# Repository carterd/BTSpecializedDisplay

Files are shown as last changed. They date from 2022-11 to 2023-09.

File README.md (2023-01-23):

# Bluetooth Specialized Display (https://https://github.com/carterd/BTSpecializedDisplay)

Ebike display for Specialized Turbo bikes, these include Kenevo/Levo/Creo.

# Configuration

If your using the Arduino IDE to compile the software you'll need to place each of the dependencies into the 'Arduino/library'
folder, and install the BTSpecializedDisplay project files into 'Arduino/BTSpecializedDisplay'. In addition you will need to 
copy the file "lv_conf.h" from of the location 'Arduino/library/BTSpecializedDisplay/lv_conf.h' to the location 
'Arduino/library/lv_conf.h'. This will ensure the lvgl library is configured correctly for RP2040 and Adafruit libraries.

Take special note of the version of LVGL your using ... if your decide to use the latest from the GIT repository you'll need
to make specific changes to the file 'Arduino/library/Adafruit_LvGL_Glue/src/Adafruit_LvGL_Glue.h', lines 4-5. 

# Dependencies
 
 * [ArduinoBLE (carterd version)](https://github.com/carterd/ArduinoBLE)

    As of writting this readme, ArduinoBLE 1.3.2 has a bug and needs patching hence clone the above branch into your
    Arduino/library path.

 * [Arduino LvGL Glue Library](https://github.com/carterd/Arduino_LvGL_Glue) 

    This is my own version of the Adafruit LvGL Glue, and hence you'll need to clone the branch to Arduino/library path.
    The library provides driver implementation for various graphics displays with LVGL.
    
 * [LittlevGL](https://github.com/littlevgl/lvgl)

    As of writting the code, the application has been written against version 8.3 of LVGL. Hence, I'd advise using the
    latest version 8.3.4 of LVGL (as of writting). Note, to copy the "lv_conf.h" out of Adafruit_LvGL_Glue above.
    
    You can use the latest lvgl source from github, but there has been a change to the debug API and hence this will 
    require you to patch my Adafruit LvGL Glue Library. Hence, if your not confident in coding skills then use LVGL version
    8.3.4.

 * [Adafruit GFX Library](https://github.com/adafruit/Adafruit-GFX-Library)

    As of writting the code, the application has been written against version 1.11.3 of Adafruit GFX Library. We'll need
    this to drive the Adafruit OLED 128x64 FeatherWing.

 * [Adafruit SH110X Library](https://github.com/adafruit/Adafruit_SH110X)

    As of writting the code, the application has been written against version 2.1.6 of Adafruit SH110X Library. We'll need
    this to drive the SH110X display. Hence other types of display may mean you don't require this library.

 * [Arduino Encorder](https://github.com/carterd/Arduino_Encoder)

    The LvGL library has a concept of an encoder, this library implements a generic framework for such an encoder as well
    as a three button encoder implementation which is compatable with the three buttons on the Adafruit OLED 128x64 FeatherWing.

 * [Adafruit_TouchScreen](https://github.com/adafruit/Adafruit_TouchScreen)

    When re-writting the Adafruit LvGL Glue Library, the touch-screen code was maintained, hence even though SH110X display
    has buttons and not touchscreen, some touch screen code is left in LvGL Glue Library and hence requires this library
    unless you explicitly remove these references to touch screens.

 * [MBED_RPI_PICO_TimerInterrupt](https://github.com/khoih-prog/MBED_RPI_PICO_TimerInterrupt)

    This is a required RP2040 specific library specifically to create an interrupt to update the LvGL timer.
 
 * [LittleFS_Mbed_RP2040](https://github.com/khoih-prog/LittleFS_Mbed_RP2040)

    AS of writting using version 1.1.0 of LittleFS_Mbed_RP2040. An implementation of a file-system on the RP2040 hence
    allowing configuration to be stored in the flash memory of the RP2040.

# Issues

The current BLE library has an issue in the file 'src/utility/ATT.cpp' function 'ATTClass::discoverDescriptors', 
until this is fixed used the patched branch at (https://github.com/carterd/ArduinoBLE).

The application has been written using a branched version of "Adafruit LvGL Glue Library" which differs significatly
hence care should be used to use the specific dependancy identified above.

# The Circuit

Please see [a relative link](circuit/Readme.md) for more details on the specifics of the hardware components and
details of wiring.

# The Enclosure

An example enclosure has been designed in Blender the assoicated .blend file of this enclosure can be found in the
directory ./enclosure, as well as a number of .STL files of the individual parts that comprise the
enclosure, see [a relative link](enclosure/Readme.md).

# Copyright Notice

Bluetooth Display for Specialized Turbo bikes
Copyright (C) 2022 Derek Carter

This program is free software: you can redistribute it and/or modify
it under the terms of the GNU General Public License as published by
the Free Software Foundation, either version 3 of the License, or
(at your option) any later version.

This program is distributed in the hope that it will be useful,
but WITHOUT ANY WARRANTY; without even the implied warranty of
MERCHANTABILITY or FITNESS FOR A PARTICULAR PURPOSE.  See the
GNU General Public License for more details.

You should have received a copy of the GNU General Public License
along with this program.  If not, see <http://www.gnu.org/licenses/>.

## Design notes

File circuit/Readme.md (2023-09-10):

# Bluetooth Specialized Display Circuit Diagram (https://github.com/carterd/BTSpecializedDisplay)

I've created a number of versions of the Bluetooth Specialized Display based on the the following:

 * Arduino Nano RP2040 Connect

 * TTGO T-Display

 * T-Display-S3

Each circuit is designed to plug into the Brose motors which are compatable with 6v lights. The compatibility 
for such motors can be found here for the Lupine lights https://www.lupine.de/eng/service/downloads/66-3.

Therefore we see that if we limit the Display circuit to max of 6v input the circuit is compatible with:

 * Gen 1 Motors
 * Gen 1.2 / 1.2E / 1.2S Motors
 * Gen 1.3 Motors

# Converting to use universal E-Bike connectors

In order to give a cheap universal connection for display and lights a Brose to universal E-Bike connector
lead can be implemented as follows:

```
Two pin E-bike "RED" connector

               ┌────────┐─────┐                            ┌────┌─────────┐     ┌────────┐─────┐
              ┌┘        └┐    └┐ 6V (Red)         (White) ┌┘   ┌┘         └┐   ┌┘        └┐    └┐ 6V (White)     
              │    ===== │     ├──────────────────────────┤    │     O     │   │    ===== │     ├───────────────────────   
     Brose    │         ┌┘     │                          │    │          ┌┘   └┐         │     │                           Bluetooth 
              │         │      │                          │    │          │     │         │     │
     Motor    │         └┐     │ 0V (Black)       (Black) │    │          └┐   ┌┘         │     │ 0V (Black)                Display
              │    ===== │     ├──────────────────────────┤    │     O     │   │    ===== │     ├───────────────────────   
              └┐        ┌┘    ┌┘                          └┐   └┐         ┌┘   └┐        ┌┘    ┌┘ 
               └────────┘─────┘                            └────└─────────┘     └────────┘─────┘ 
                Lupine/Exposure                             E-bike 2 pin RED
                Male Connector                              Female Connector

Five pin E-bike "GREEN" connector

               ┌────────┐─────┐                            ┌────┌─────────┐     ┌────────┐─────┐
              ┌┘        └┐    └┐ 6V (Red)                 ┌┘   ┌┘         └┐   ┌┘        └┐    └┐ 6V ([R]ed [B]lu[E])     
              │    ===== │     ├──────────────────────────┤    │   O   O   │   │  BE= G== │     ├───────────────────────   
     Brose    │         ┌┘     │                          │    │          ┌┘   └┐         │     │                            Bluetooth 
              │         │      │                          │    │  O       │     │      Y= │     │
     Motor    │         └┐     │ 0V (Black)               │    │          └┐   ┌┘         │     │ 0V ([B]lac[K] [G]reen)     Display
              │    ===== │     ├──────────────────────────┤    │   O   O   │   │  R== BK= │     ├───────────────────────
              └┐        ┌┘    ┌┘                          └┐   └┐         ┌┘   └┐        ┌┘    ┌┘ 
               └────────┘─────┘                            └────└─────────┘     └────────┘─────┘ 
                Lupine/Exposure                             E-bike 5 pin GREEN
                Male Connector                              Female Connector

```

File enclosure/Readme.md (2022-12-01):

# Bluetooth Specialized Display Enclosure (https://github.com/carterd/BTSpecializedDisplay)

This Readme descibes the files of 3D models for the enclosure of an external Ebike display for Specialized Turbo bikes, 
these include Kenevo/Levo/Creo.

# The Files

The enclosure is designed in Blender, and an associated .blend file is included. As well as each individual component exported as an STL file as follows:

 * SpecializedDisplay.blend

    This blend file contains the following Collection of objects:

    * CaseFloor - The bottom of the enclosure and have attempted to include a curve surface in an attempt to match the toptube
                  of a bike.

    * Controller - A reference object to show the rough dimensions of the Arduino Nana RP2040 Connect.

    * Display - A reference object to show the rough dimensions of the Adafruit 128x64 OLED display and the position of it's buttons.

    * LongButton - This is the 3 push buttons which should be filled down in order that they are the correct length for contact with
                   the buttons of the Adafruit 128x64 OLED display.

    * RoundCase - The main case body for both the Adafruit 128x64 OLED display, and the Arduino Nana RP2040 Connect.

    * RoundCaseTop - The top cover of the encolsure.

 * SpecializedDisplayButtons.stl - Exported STL file of the LongButton object from the SpecializedDisplay.blend file.

 * SpecializedDisplayCase.stl - Exported STL file of the RoundCase object from the SpecializedDisplay.blend file.
 
 * SpecializedDisplayFloor.stl - Exported STL file of the CaseFloor object from the SpecializedDisplay.blend file.

 * SpecializedDisplayTop.stl - Exported STL file of the RoundCaseTop object from the SpecializedDisplay.blend file.

 # Construction

 After printing the four STL files, SpecializedDisplayButtons.stl, SpecializedDisplayCase.stl, SpecializedDisplayFloor.stl, SpecializedDisplayTop.stl; modification with sand-paper and/or file maybe required for them to snugly fit together.

 In order to attempt to water proof the device, I've glued in place a clear plastic film over the display appature of the
 SpecializedDisplayTop part of the enclosure.

 Then the SpecializedDisplayTop and SpecializedDisplayCase parts are glued together.

 The SpecializedDisplayButtons parts are filed down till they function correctly with the Adafruit display correctly fitted.
 Then the buttons are glued in place while still allowing the buttons to actuate correctly.

 Then apply a thin layer of Latex Rubber in the gaps between buttons and case in an attempt to provide a waterproof barrier.
 Taking care not to cover any of the clear plastic film over the display appature.

 Finally use the SpecializedDisplayFloor as a template for drilling 1mm holes into the SpecializedDisplayCase and use very
 small M1.2 or M1.4 screws to fix the floor into place.

 I did not find the need to pack behind either the Arduino Nana RP2040 Connect, or Adafruit 128x64 OLED display but this
 maybe required if these components are found to be loose within the enclosure.

 # Mounting

 The enclosure is designed to be mounted on the top-tube of the bike, and a power cable running from the Display can be routed
 to the Brose motor where 6 volts outputs are provided for front and rear lights. 
 
 # Connection
 
 For connection to the Brose Motor use something like:

   * Exposure E-Bike Light Connector - Brose 

   * Lupine Light Cable for E-Bike - Brose

Additional lengths from the brose Motor connector to the Display mounted on the top-tube can be implemented using more standard
Ebike Julet Waterproof connectors.

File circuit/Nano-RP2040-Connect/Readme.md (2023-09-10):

# Bluetooth Specialized Display Circuit Diagram (https://github.com/carterd/BTSpecializedDisplay)

This Readme descibes the components and circuit connections for the external Ebike display for Specialized Turbo bikes, 
these include Kenevo/Levo/Creo, based upon the Arduino Nano PR2040 Connect and the SH1107 OLED display.

# Components

The circuit for the software is based on two components these are as follows:

 * Arduino Nano RP2040 Connect, https://docs.arduino.cc/hardware/nano-rp2040-connect

 * Adafruit 128x64 OLED Featherwing, https://learn.adafruit.com/adafruit-128x64-oled-featherwing

# Wiring Diagram

The wiring diagram is as follows:
```
      ┌──────────────────────────────────────────────────────────────┐
      │                                                              │
   ┌──┼────────────────────────────────────────────────────────────┐ │
   │  │                                                            │ │
┌──┼──┼──────────────────────────────────────────────────────────┐ │ │
│  │  │                                                          │ │ │
│  │  │  ┌───────────────────────────────────────────────────┐   │ │ │
│  │  │  │                                                   │   │ │ │
│  │  │  │  ┌────────────────────────────────────────────────┼─┐ │ │ │
│  │  │  │  │                                                │ │ │ │ │           ┌───────────┐
│  │  │  │  │    ┌───────┐                  ┌───────┐        │ │ │ │ │   ┌───────┤           ├───────┐
│  │  │  │  │    │       │                  │       │        │ │ │ │ │   │    GRN│           │ORG    │
│  │  │  │  │    │       └──────────────────┘       │        │ │ │ │ │   │    LED│   Micro   │LED    │
│  │  │  │  │    │                                  │        │ │ │ │ │   │       │    USB    │       │
│  │  │  │  └────┤SDA ┌────────────────────────┐    ├──      │ │ │ │ │ ──┤D13    │           │    D12├──
│  │  │  │       │    │                        │    │        │ │ │ │ │   │       │           │       │
│  │  │  └───────┤SCL │                        │    ├── ┌────┼─┼─┼─┼─┼───┤+3V3   └───────────┘    D11├──
│  │  │          │    │                        │    │   │    │ │ │ │ │   │                           │
│  │  └──────────┤ A  │                        │    ├── │    │ │ │ │ │ ──┤AREF                    D10├──
│  │             │    │                        │    │   │    │ │ │ │ │   │                           │
│  └─────────────┤ B  │                        │    ├── │    │ │ │ │ └───┤D14                      D9├──
│                │    │                        │    │   │    │ │ │ │     │                           │
└────────────────┤ C  │         128x64         │    ├── │    │ │ │ └─────┤D15                      D8├──
                 │    │       Monochrome       │    │   │    │ │ │       │                           │
               ──┤    │    OLED FeatherWing    │    ├── │    │ │ └───────┤D16                      D7├──
                 │    │         SH1107         │    │   │    │ │         │         ARDUINO           │
               ──┤    │                        │    ├── │  ┌─┼─┼─────────┤D17        NANO          D6├──
                 │    │                        │    │   │  │ │ │         │          RP2040           │
               ──┤    │                        │    ├── │  │ │ └─────────┤SDA      CONNECT         D5├──
                 │    │                        │    │   │  │ │           │                           │
               ──┤    │                        │    ├── │  │ └───────────┤SCL                      D4├──
                 │    │                        │    │   │  │             │                           │
               ──┤    │                        │    ├── │  │           ──┤D20                      D3├──
                 │    │                        │    │   │  │             │                           │
               ──┤    │                        │    ├── │  │           ──┤D21                      D2├──
                 │    │                        │    │   │  │             │                           │
               ──┤    │                        │    ├── │  │           ──┤+5V                     GND├──
                 │    │                        │    │   │  │             │                      _____│
                 │    │                        │    ├── │  │           ──┤REC  ┌───────────────┐RESET├──
                 │    └────────────────────────┘    │   │  │             │     │               │     │
                 │                               GND├───┼──┼──────█──────┤GND  │               │   RX├──
                 │ ┌───┐                            │   │  │      │      │     │               │     │
                 │ │   │  ┌───┐  ┌───┐  ┌───┐     3V├───┘  │      │  ┌───┤VIN  │               │   TX├──
                 │ │ O │  │   │  │   │  │   │       │      │      │  │   │     │               │     │
                 │ │   │  │ O │  │ O │  │ O │    RST├──────┘      │  │   │     ├─┬─────────────┤     │
                 │ └───┘  │   │  │   │  │   │       │             │  │   │     │ │┼┼┼┼┼┼┼┼┼┼┼┼┼│     │
                 │        └───┘  └───┘  └───┘       │             │  │   └─────┴─┴─────────────┴─────┘
                 │                                  │             │  │
                 └──────────────────────────────────┘             │  │
                                                                  │  │
                                                                  │  │
                   POWER LEAD GND         ────────────────────────┘  │
                                                                     │
                   POWER LEAD 4-20V       ───────────────────────────┘
```
The pinouts of the two components are as follows, for the Arduino Nano RP2040 Connect as follows:

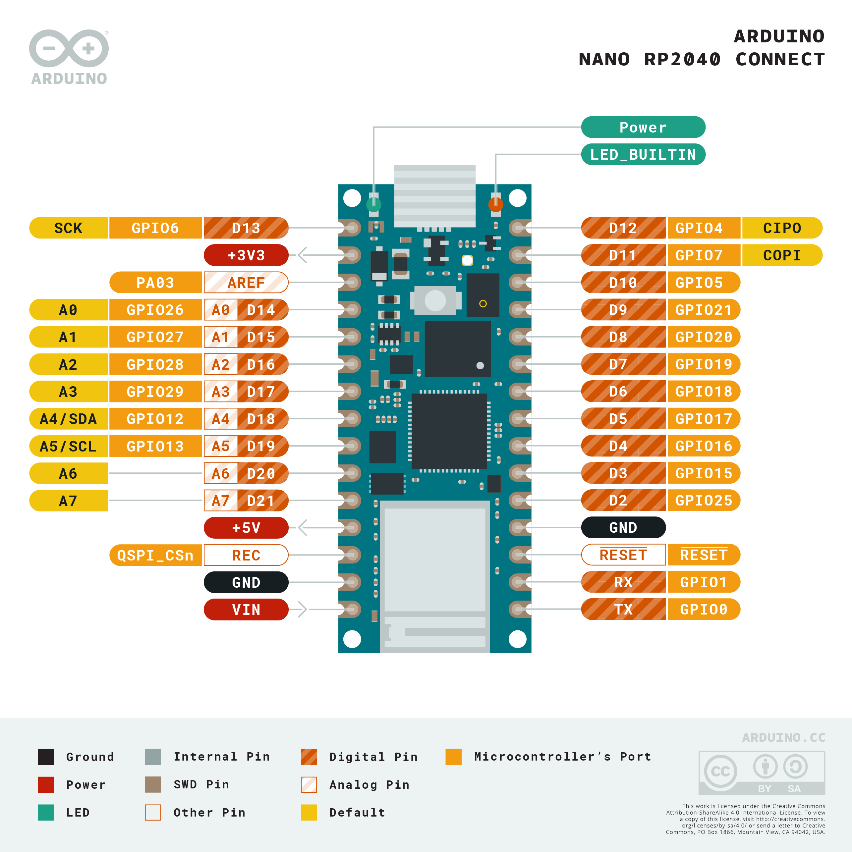
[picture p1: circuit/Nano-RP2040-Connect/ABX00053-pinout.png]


Note that for the pinouts for the Adafruit OLED 128x64 the image below is showing the view from the bottom of device, whereas in the circuit diagram above the 128x64 is shown from above.

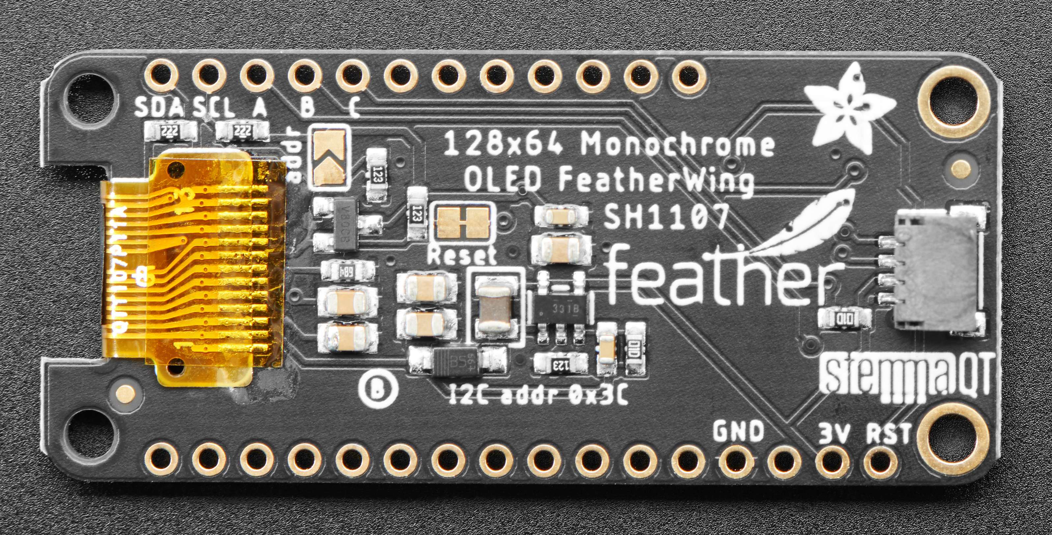
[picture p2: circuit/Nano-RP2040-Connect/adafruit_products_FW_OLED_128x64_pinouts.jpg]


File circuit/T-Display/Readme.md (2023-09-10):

# Bluetooth Specialized Display Circuit Diagram (https://github.com/carterd/BTSpecializedDisplay)

This Readme descibes the components and circuit connections for the external Ebike display for Specialized Turbo bikes, 
these include Kenevo/Levo/Creo, this is based upon the TTGO T-Display.

# Components

The circuit for the software is based on a single component:

 * TTGO-T-Display, https://github.com/Xinyuan-LilyGO/TTGO-T-Display

# Wiring Diagram

The wiring diagram is as follows:
```

       ┌───────────────────────────┐
       │                           │
       │           TTGO            │
       │                           │
     ──┤GND                    +3V3├──
       │                           │
     ──┤GND                      36├──
       │                           │
     ──┤21                       37├──
       │                           │
     ──┤22                       38├──
       │                           │
     ──┤17                       39├──
       │                           │
     ──┤2                        32├──
       │           TTGO            │
     ──┤15       T-DISPLAY       33├──
       │                           │
     ──┤13                       25├──
       │                           │
     ──┤12                       26├──
       │                           │
     ──┤GND                      27├──
       │                           │
     ──┤GND                     GND├───────────────────────── POWER LEAD GND
       │                           │
     ──┤+3V3                    +5V├──────────────────|<───── POWER LEAD 6V
       │                           │                Diode
       │                           │               1N4007
       │                           │
       │                           │
       │     ┌───────────────┐     │
       │     │               │     │
       │ BTN │     USB-C     │ BTN │
       │     │               │     │
       └─────┤               ├─────┘
             └───────────────┘ 

```
The pinouts of the two components are as follows, for the Arduino Nano RP2040 Connect as follows:



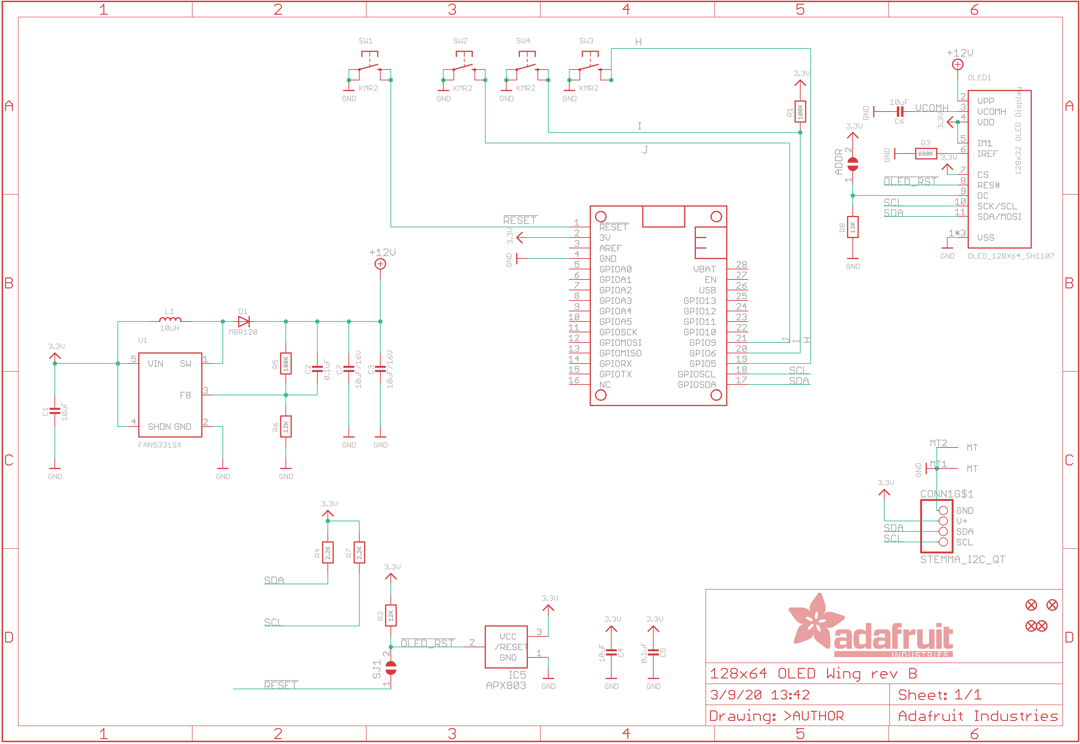
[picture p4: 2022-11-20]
circuit/Nano-RP2040-Connect/adafruit_products_FW_OLED_128x64_sch.png

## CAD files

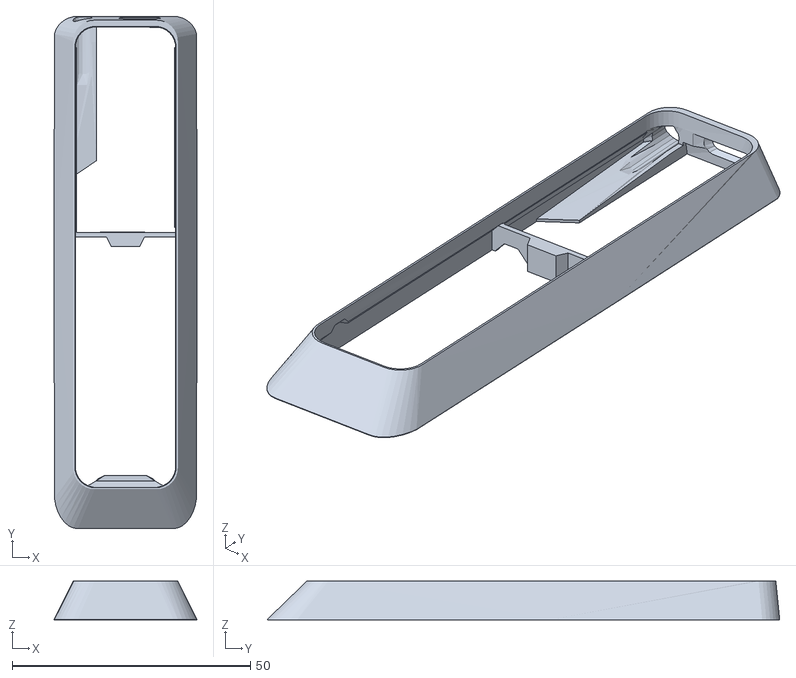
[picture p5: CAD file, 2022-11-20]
enclosure/SpecializedDisplayCase.stl
30.0 x 107.5 x 8.10

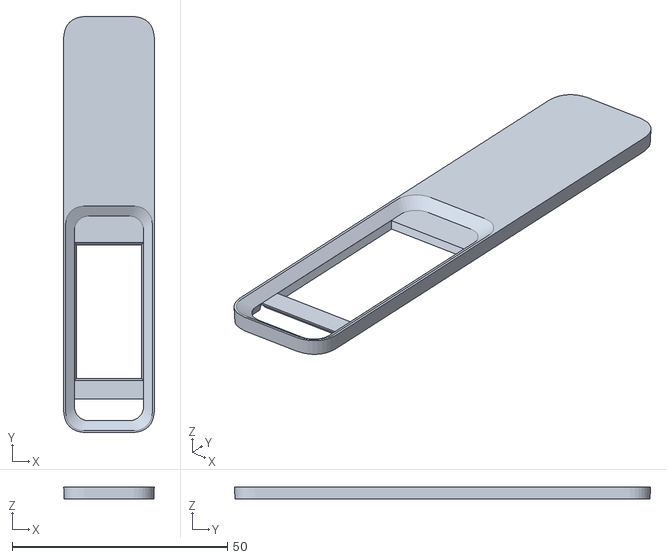
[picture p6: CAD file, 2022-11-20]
enclosure/SpecializedDisplayTop.stl
21.0 x 96.6 x 2.80

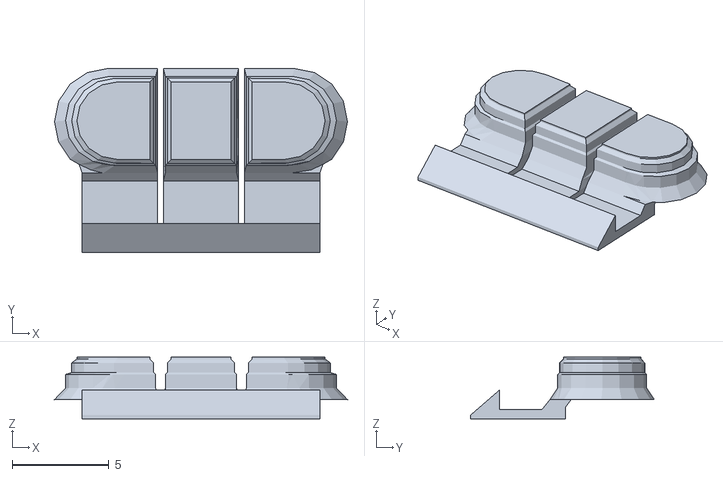
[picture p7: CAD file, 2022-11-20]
enclosure/SpecializedDisplayButtons.stl
15.1 x 9.50 x 3.20

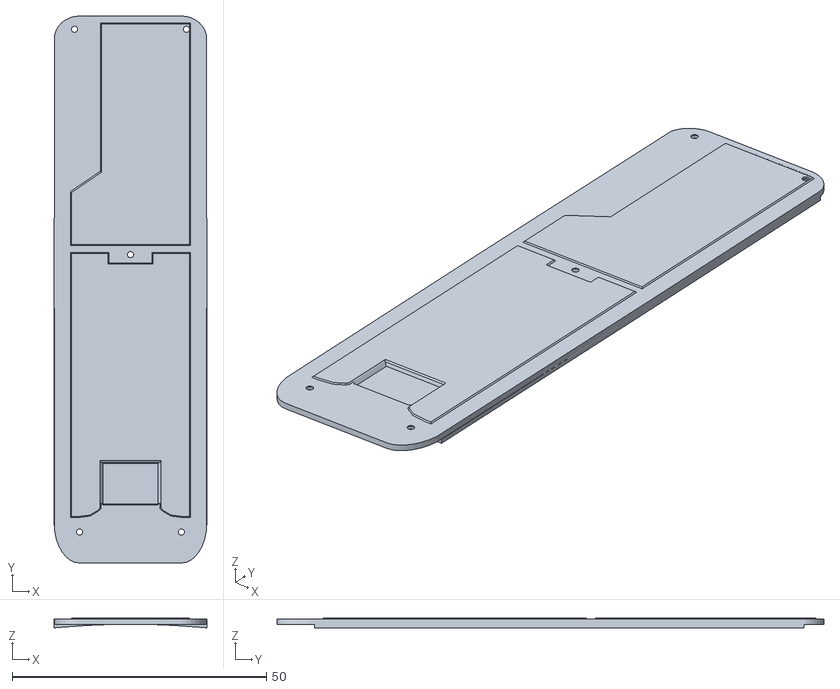
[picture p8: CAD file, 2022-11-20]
enclosure/SpecializedDisplayFloor.stl
30.0 x 107.5 x 1.90

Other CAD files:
enclosure/SpecializedDisplay.blend
enclosure/SpecializedDisplay_NanoRP2040Connect_SH107.blend
enclosure/SpecializedDisplay_TDisplay.blend

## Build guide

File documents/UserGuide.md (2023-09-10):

# Bluetooth Specialized Display User Guide

## Installation

This is incomplete at this time.

## Operating

### Buttons

The display will have either two or three buttons, these buttons are [LEFT], [SELECT] 
and [RIGHT]. In the case of a two button display the user is required to press both [LEFT] and 
[RIGHT] buttons concurrently in order to 'press' [SELECT].

### Turning on the display

If the display has been wired into the Brose motor the display will turn on as soon as the bike is 
turned on. The display can also be powered by a USB connection if the user wishes not to connect
the display to the bike motor.

**WARNING: It is advised not to connect the displays USB while the bike it turned on.**

Once the display is turned on the user can navigate between the three main functional areas of the
display using [LEFT] and [RIGHT]. The three main functional areas are as follows:

 * LET'S RIDE - Connect to the bike for displaying information while riding the bike.

 * CONFIGURE - Configure the settings of the display and the bike.

 * PAIR BIKE - Ensure the display correctly connects to your specific e-bike.

On selecting the correct functional area the user should press [SELECT] in order to enter the
currently selected functional area.

### Pairing Your Bike

This is probably the first step in configuring the display, in order for the display to connect
to the user's e-bike they'll need to pair the display with the bike. This is done by selecting
the 'PAIR BIKE' functional area.

Once 'PAIR BIKE' is selected the display will start searching for your e-bike therefore it's
important to ensure the e-bike that you wish to connect to is turned on, and is not currently 
connected to any other devices. Therefore, if the bike has already been paired with other 
devices such as phones or bike-computers ensure that these devices are no-longer attempting
to connect to the e-bike.

The display at this point should display 'Scanning ...' and show any Bluetooth divces that
are possible to connect to. The user should use [LEFT] and [RIGHT] buttons to navigate to
the Bluetooth device which is their e-bike, and press [SELECT] once that device is highlighted.
A tick should appear next to the deivce that the display is paired with.

In the case of owning multiple batteries for your e-bike, each battery will be identified as
a different device. Therefore the display is able to paired with multiple devices, and hence
on connecting searches for the first device with which it has been paired with that it can
connect to.

Once the e-bike has been selected then the user should navigate to the 'EXIT' and press
[SELECT].

If you wish to remove a paired device then select the 'PAIR BIKE' functional area.
And all paired bikes will be shown in the list even if those devices are nolonger in range
or turned on. Hence the user is able to navigate to the specific device they wish to
un-pair using [LEFT] and [RIGHT] buttons and on pressing [SELECT] while highlighting 
the device they wish to unpair the tick is removed agaist the device and the user should now
navigate to the 'EXIT' option adn press [SELECT].

### Connecting to the Bike

Once the bike has been successfully paired with the display the display can be connected to
the bike by navigating to the main functional area 'LET'S RIDE'.

On selecting 'LET'S RIDE' a green 'spinner' should appear on the display this represents the
display attempting to search and connect to the e-bike. This should normally take about 5 to
10 seconds for the display to connect to the bike. If it's taking eccessive time then it maybe
the bike is already connected with a different device or the display is no-longer paired with
the bike.

Once the display has successfully connected to the bike, one of the bike status screens should
be displayed. The user can then use [LEFT] and [RIGHT] buttons to navigate to the screen they
wish to ride with.

If the user wishes to return to the main functional areas they should hold [SELECT] for about
a second, and release and the display should disconnect from the e-bike and the display returned
to navigating the three main functional areas.

### Configuring the Display

In order to configure the display the user should navigate to the 'CONFIGURE' functional area.

On selecting 'CONFIGURE' a menu is displayed with options to 'EXIT' the configuration or
configure either the bike or the display. The user sould therefore use [LEFT] and [RIGHT]
buttons to navigate to the 'Display' option and press [SELECT].

The following display options are available:

 * Brightness - How bright the display is.

 * Units - If the display should use metric or imperial units.

 * On Start - If the display should attempt to connect to the bike on being turned on.

 * Connection - If the display should attempt to connect to batteries that are not installed the bike.

 * Assist Presets - Manage a number of preset bike asssit levels.

### Configuring the Bike

In order to configure the bike the user should navigate to the 'CONFIGURE' functional area.

On selecting 'CONFIGURE' a menu is displayed with options to 'EXIT' the configuration or
configure either the bike or the display. The user sould therefore use [LEFT] and [RIGHT]
buttons to navigate to the 'Bike' option and press [SELECT].

The following bike options are available:

 * Beeper - If the bike makes a beep on changing the assist levels between 'Eco', 'Trail' and 'Turbo'

 * Assist Levels - The level of assist provided by each of the assist levels 'Eco', Trail' and 'Turbo'

 * Wheel Circumference - Due to restrictions on the bike firmware this will have no affect on the bikes
                         configuration but will affect the calculation of speed used by the display.

### Resetting the Display

In order to reset the display, removing all the paired devices and reseting configuration to the 
default settings the user should hold down [RIGHT] button during turning the display on.

The user should hold [RIGHT] button while the display shows a dot getting larger and larger. If the
users releases the button before the screen is completely filled by the dot the display will not be
reset. Only by holding the [RIGHT] button until the screen has been completely coloured white will
the display be reset.

## Updates and Re-programming

This is incomplete at this time.

# Copyright Notice

Bluetooth Display for Specialized Turbo bikes
Copyright (C) 2023 Derek Carter

This program is free software: you can redistribute it and/or modify
it under the terms of the GNU General Public License as published by
the Free Software Foundation, either version 3 of the License, or
(at your option) any later version.

This program is distributed in the hope that it will be useful,
but WITHOUT ANY WARRANTY; without even the implied warranty of
MERCHANTABILITY or FITNESS FOR A PARTICULAR PURPOSE.  See the
GNU General Public License for more details.

You should have received a copy of the GNU General Public License
along with this program.  If not, see <http://www.gnu.org/licenses/>.

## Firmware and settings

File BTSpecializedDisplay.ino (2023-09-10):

#include <Arduino.h>
#include <Wire.h>

#include <Arduino_LvGL_Glue.h>
#include <ButtonEncoder.h>
#include "Hardware.h"

#include "LedError.h"
#include "src/LvglGui.h"
#include "src/dev/BluetoothController.h"
#include "src/dev/BluetoothBike.h"
#include "src/dev/BluetoothHeartRateMonitor.h"
#include "src/dev/BluetoothScanner.h"

#define MIN_RESET_BUTTON_PRESS_TIME_MS 10 * 1000
#define _SERIAL_DEBUG 1

/**
 * @brief Arduino displayGlue static
 */
static Arduino_LvGL_Glue displayGlue;

/**
 * @brief Statics kept around
 * 
 */
BluetoothScanner* bluetoothScanner;
BluetoothBike* bluetoothBike;
BluetoothHeartRateMonitor* bluetoothHeartRateMonitor;
BluetoothController* bluetoothController;
ConfigStore* configStore;

bool resetButtonTest(Encoder* encoder) {
    // Specific de-bounce for two button encoders
    encoder->update();
    unsigned long startTime = millis();
    do {
        unsigned long radius =  (millis() - startTime) / (MIN_RESET_BUTTON_PRESS_TIME_MS / DISPLAY_WIDTH);
        encoder->update();
        if ((encoder->keyPressed() && encoder->lastKeyPressed() == Encoder::EncoderKey::ENCODER_RIGHT)) {
            displayfillCircle(radius);      
        }
    } while (encoder->keyPressed() && encoder->lastKeyPressed() == Encoder::EncoderKey::ENCODER_RIGHT);
    if (millis() - startTime > MIN_RESET_BUTTON_PRESS_TIME_MS) return true;
    return false;
}

void setup() {
    // Allow time for display to wake up
    delay(250);
    pinMode(LED_BUILTIN, OUTPUT);

#if _SERIAL_DEBUG == 1
    // Remote if no serial monitor
    Serial.begin(115200);
    while (!Serial);
#endif

    if (!BLE.begin()) {
        //Serial.println("starting BLE failed!");
        while (1);
    }

    // Initialise display
    LvGL_DisplayBase* lvglDisplay = displayInit();

    // Initialise the encoder
    Arduino_ButtonEncoder_LvGL_Input* lvglInput = encoderInit();

    // Initialise display glue
    LvGLStatus result = displayGlue.begin(lvglDisplay, lvglInput, true);
    if (result != LVGL_OK) {    
        led_error(result);
    }
    
    bluetoothScanner = new BluetoothScanner();
    bluetoothBike = new BluetoothBike();
    bluetoothHeartRateMonitor = new BluetoothHeartRateMonitor();
    bluetoothController = new BluetoothController(bluetoothBike, bluetoothHeartRateMonitor, bluetoothScanner, BLE_CONNECTION_REQUIRES_SCAN_STOP);
    
    configStore = new ConfigStore(FS_FILE_PREFIX FS_SEPARATOR "knownDevices.bin", FS_FILE_PREFIX FS_SEPARATOR "bikeConfig.bin", FS_FILE_PREFIX FS_SEPARATOR "displayConfig.bin", FS_FILE_PREFIX FS_SEPARATOR "saves");

    static FileSystem fileSystem;
    configStore->init(&fileSystem);

    if (resetButtonTest(lvglInput->getButtonEncoder())) {
        configStore->writeDefaults();
    }
    
    if (configStore->readBTAddressMap() && configStore->readBikeConfig() && configStore->readDisplayConfig() && configStore->savesConfig()) {
    } else {
        LV_LOG_ERROR("Error reading config files, initialise default config.");
        configStore->writeDefaults();
    }

    lv_disp_t *display = displayGlue.getLvDisplay();
    lv_indev_t *indev = displayGlue.getLvInputDevice();

    // initialise the binary theme
    lv_theme_t* theme = themeInit(displayGlue.getLvDisplay());
    //lv_theme_t* binary_theme = lv_theme_binary_init(displayGlue.getLvDisplay(), true, &myAdaFont);
    //lv_theme_t* default_theme = lv_theme_default_init(displayGlue.getLvDisplay(), lv_color_make(0xff,0xff,0xff), lv_color_make(0xff,0x80,0x80), true, &lv_font_montserrat_28);

    lv_disp_set_rotation(NULL, LV_DISP_ROT_180);
    lv_disp_set_theme(display, theme);
    //lv_disp_set_theme(display, default_theme);

    lvgl_setup(configStore, bluetoothController, bluetoothBike, bluetoothHeartRateMonitor, bluetoothScanner, displayGlue, indev);
}

void loop() {
  // put your main code here, to run repeatedly:
  lv_task_handler(); // Call LittleVGL task handler periodically
  unsigned long start = millis();
  
  bluetoothBike->checkForChange();
  bluetoothScanner->checkForChange();

  unsigned long end = millis();
  if (start <= end && end - start < 20) {
    delay(20 + start - end);
  }
}

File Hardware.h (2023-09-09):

#ifndef _DISPLAY_DEVICE_H_
#define _DISPLAY_DEVICE_H_

#include <Arduino_LvGL_Glue.h>
#include <LvglInputs/Arduino_ButtonEncoder_LvGL_Input.h>
#include "src/dev/ConfigStore.h"

///////////////////////////////////////////////////////////////////////////////////////////////////
// Config of the Display under the RP2040 which will be ADAFRUIT_SH110X
///////////////////////////////////////////////////////////////////////////////////////////////////
#ifdef ARDUINO_ARCH_RP2040

// Bluetooth
//
#define BLE_CONNECTION_REQUIRES_SCAN_STOP true

// Encoder
//
#include <ThreeButtonEncoder.h>
#define ENCODER_LEFT_PIN 16
#define ENCODER_RIGHT_PIN 14
#define ENCODER_SELECT_PIN 15
#define ENCODER_PRESSED_STATE LOW
#define ENCODER_BUTTON_PIN_MODE INPUT_PULLUP
static ThreeButtonEncoder encoder(ENCODER_LEFT_PIN, ENCODER_RIGHT_PIN, ENCODER_SELECT_PIN, ENCODER_PRESSED_STATE, ENCODER_BUTTON_PIN_MODE);

Arduino_ButtonEncoder_LvGL_Input* encoderInit() {
    static Arduino_ButtonEncoder_LvGL_Input lvglInput(&encoder);
    return &lvglInput;
}

// Display Stuff
//
#include <Adafruit_GFX.h>
#include <Adafruit_SH110X.h>
#include <LvglDisplays/Adafruit_SH110X_LvGL_Display.h>
#define ADAFRUIT_SH1107_RESET_D_PIN 20
#define DISPLAY_WIDTH 64
#define DISPLAY_HEIGHT 128

static Adafruit_SH1107 displayDevice(DISPLAY_WIDTH, DISPLAY_HEIGHT, &Wire, ADAFRUIT_SH1107_RESET_D_PIN);

LvGL_DisplayBase* displayInit() {
    bool displayWorking = false;
    while (!displayWorking) {
        displayWorking = displayDevice.begin(0x3C, true); // Address 0x3C default
        digitalWrite(LED_BUILTIN, HIGH);            // turn the LED on (HIGH is the voltage level)
        if (!displayWorking) delay(2000);           // wait for a second
    };
    displayDevice.clearDisplay();
    displayDevice.display();

    static Adafruit_SH110X_LvGL_Display lvglDisplay(&displayDevice);
    return &lvglDisplay;
}

#include <Fonts/PixelOperator8pt7b.h>
#include "src/themes/lv_theme_SH1107.h"
#include <LvglFonts/lv_font_symbols_8.h>
#include <Utilities/Adafruit_To_LvGL_Font.h>

lv_theme_t* themeInit(lv_disp_t *disp) {
    static lv_font_t myAdaFont = {};
    adafruitToLvGLFont(&PixelOperator8pt7b, &myAdaFont, &lv_font_symbols_8);
    return lv_theme_sh1107_init(disp, true, &myAdaFont);
}

void displayfillCircle(unsigned long radius) {
    displayDevice.fillCircle(displayDevice.width() / 2, displayDevice.height() / 2, radius, SH110X_WHITE);
    displayDevice.display();
}

void displaySetContrast(void *display, int contrastLevel) {
    switch (contrastLevel) {
        case 0:
            contrastLevel = 0x01;
            break;
        case 1:
            contrastLevel = 0x14;
            break;
        case 2:
            contrastLevel = 0x2F;
            break;
    }
    ((Adafruit_SH1107*) display)->setContrast(contrastLevel);
}

// File System
//

#define FORCE_REFOMAT false;
#define RP2040_FS_SIZE_KB 64
#define LFS_MBED_RP2040_DEBUG 1
#define _LFS_LOGLEVEL_ 100
#include <Arduino.h>
#include <LittleFS_Mbed_RP2040.h>
#define FS_FILE_PREFIX MBED_LITTLEFS_FILE_PREFIX
#define FS_SEPARATOR "/"

bool FileSystem::init() {
    this->fileSystem = new LittleFS_MBED();
    if (!((LittleFS_MBED*)(this->fileSystem))->init()) {
        return false;
    }
    return true;
}
bool FileSystem::openDir(const char* dirPath) {
    this->dir = opendir(dirPath);
    if (this->dir) return true;
    return false;
}
bool FileSystem::closeDir() {
    if (this->dir) {
        closedir((DIR*)this->dir);
        return true;
    }
    return false;
}
bool FileSystem::mkDir(const char* dirPath) {
    if (mkdir(dirPath, S_IRWXU | S_IRWXG | S_IRWXO) == 0) return true;
    return false;
}

bool FileSystem::readDir(char* fileName, int maxFileName) {
    static struct dirent* pDirent;
    if ((pDirent = readdir((DIR*) (this->dir))) == NULL) {
        return false;
    }
    strncpy(fileName, pDirent->d_name, maxFileName-1);
    fileName[maxFileName-1] = 0x00;
    return true;
}
bool FileSystem::openFile(const char* filePath, const char* mode) {
    this->file = fopen(filePath, mode);
    if (this->file) return true;
    return false;
}
bool FileSystem::readFile(void* buffer, size_t size, size_t n) {
    return fread(buffer, size, n, (FILE*) (this->file)) == n;
}
bool FileSystem::writeFile(const void* buffer, size_t size, size_t n) {
    return fwrite(buffer, size, n, (FILE*) (this->file)) == n;
}
bool FileSystem::closeFile() {
    fclose((FILE*)this->file);
    return true;
}

#endif

///////////////////////////////////////////////////////////////////////////////////////////////////
// Config of the Display for T-DISPLAY
///////////////////////////////////////////////////////////////////////////////////////////////////
#ifdef ARDUINO_TTGO_LoRa32_V1
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

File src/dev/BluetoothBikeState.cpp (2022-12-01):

#include "BluetoothBikeState.h"

BikeState::BikeState()
{
    this->bikeStateAttributes[static_cast<int>(BikeStateAttributeIndex::BATTERY_CAPACITY)].bikeStateAttributeType = BikeStateAttributeType::UINT16_T;
    this->bikeStateAttributes[static_cast<int>(BikeStateAttributeIndex::BATTERY_CAPACITY_REMAINING)].bikeStateAttributeType = BikeStateAttributeType::UINT16_T;
    this->bikeStateAttributes[static_cast<int>(BikeStateAttributeIndex::BATTERY_CHARGE_CYCLES)].bikeStateAttributeType = BikeStateAttributeType::UINT16_T;
    this->bikeStateAttributes[static_cast<int>(BikeStateAttributeIndex::BATTERY_VOLTAGE)].bikeStateAttributeType = BikeStateAttributeType::FLOAT_T;
    this->bikeStateAttributes[static_cast<int>(BikeStateAttributeIndex::BATTERY_CURRENT)].bikeStateAttributeType = BikeStateAttributeType::FLOAT_T;
    this->bikeStateAttributes[static_cast<int>(BikeStateAttributeIndex::BATTERY_HEALTH)].bikeStateAttributeType = BikeStateAttributeType::UINT8_T;
    this->bikeStateAttributes[static_cast<int>(BikeStateAttributeIndex::BATTERY_CHARGE_PERCENT)].bikeStateAttributeType = BikeStateAttributeType::UINT8_T;
    this->bikeStateAttributes[static_cast<int>(BikeStateAttributeIndex::BATTERY_TEMP)].bikeStateAttributeType = BikeStateAttributeType::UINT8_T;
    this->bikeStateAttributes[static_cast<int>(BikeStateAttributeIndex::BATTERY_HARDWARE_VERSION)].bikeStateAttributeType = BikeStateAttributeType::HARDWARE_VERSION;
    this->bikeStateAttributes[static_cast<int>(BikeStateAttributeIndex::BATTERY_FIRMWARE_VERSION)].bikeStateAttributeType = BikeStateAttributeType::FIRMWARE_VERSION;
    this->bikeStateAttributes[static_cast<int>(BikeStateAttributeIndex::BATTERY_SERIAL_NUMBER)].bikeStateAttributeType = BikeStateAttributeType::UINT16_T;
    this->bikeStateAttributes[static_cast<int>(BikeStateAttributeIndex::RIDER_POWER)].bikeStateAttributeType = BikeStateAttributeType::UINT16_T;
    this->bikeStateAttributes[static_cast<int>(BikeStateAttributeIndex::MOTOR_CADENCE)].bikeStateAttributeType = BikeStateAttributeType::FLOAT_T;
    this->bikeStateAttributes[static_cast<int>(BikeStateAttributeIndex::MOTOR_SPEED)].bikeStateAttributeType = BikeStateAttributeType::FLOAT_T;
    this->bikeStateAttributes[static_cast<int>(BikeStateAttributeIndex::MOTOR_POWER)].bikeStateAttributeType = BikeStateAttributeType::UINT16_T;
    this->bikeStateAttributes[static_cast<int>(BikeStateAttributeIndex::MOTOR_ODOMETER)].bikeStateAttributeType = BikeStateAttributeType::UINT32_T;
    this->bikeStateAttributes[static_cast<int>(BikeStateAttributeIndex::MOTOR_ASSIST_LEVEL)].bikeStateAttributeType = BikeStateAttributeType::UINT16_T;
    this->bikeStateAttributes[static_cast<int>(BikeStateAttributeIndex::MOTOR_TEMP)].bikeStateAttributeType = BikeStateAttributeType::UINT8_T;
    this->bikeStateAttributes[static_cast<int>(BikeStateAttributeIndex::MOTOR_HARDWARE_VERSION)].bikeStateAttributeType = BikeStateAttributeType::HARDWARE_VERSION;
    this->bikeStateAttributes[static_cast<int>(BikeStateAttributeIndex::MOTOR_FIRMWARE_VERSION)].bikeStateAttributeType = BikeStateAttributeType::FIRMWARE_VERSION;
    this->bikeStateAttributes[static_cast<int>(BikeStateAttributeIndex::MOTOR_SERIAL_NUMBER)].bikeStateAttributeType = BikeStateAttributeType::NUMBER_STRING;
    this->bikeStateAttributes[static_cast<int>(BikeStateAttributeIndex::PEAK_POWER_ASSIST_LEVELS)].bikeStateAttributeType = BikeStateAttributeType::ASSIST_LEVELS;
    this->bikeStateAttributes[static_cast<int>(BikeStateAttributeIndex::SUPPORT_ASSIST_LEVELS)].bikeStateAttributeType = BikeStateAttributeType::ASSIST_LEVELS;
    this->bikeStateAttributes[static_cast<int>(BikeStateAttributeIndex::WHEEL_CIRCUMFERENCE)].bikeStateAttributeType = BikeStateAttributeType::UINT16_T;
    this->bikeStateAttributes[static_cast<int>(BikeStateAttributeIndex::FAKE_CHANNEL_NUMBER)].bikeStateAttributeType = BikeStateAttributeType::UINT8_T;
    this->bikeStateAttributes[static_cast<int>(BikeStateAttributeIndex::BIKE_ON_OFF_STATE)].bikeStateAttributeType = BikeStateAttributeType::UINT8_T;
    this->bikeStateAttributes[static_cast<int>(BikeStateAttributeIndex::BATTERY_CONNECTED_STATE)].bikeStateAttributeType = BikeStateAttributeType::BOOL;
    this->bikeStateAttributes[static_cast<int>(BikeStateAttributeIndex::BIKE_SERIAL_NUMBER)].bikeStateAttributeType = BikeStateAttributeType::NUMBER_STRING;
    this->bikeStateAttributes[static_cast<int>(BikeStateAttributeIndex::BEEP_ON_OFF_STATE)].bikeStateAttributeType = BikeStateAttributeType::BOOL;
    this->bikeStateAttributes[static_cast<int>(BikeStateAttributeIndex::WHEEL_ROTATIONS)].bikeStateAttributeType = BikeStateAttributeType::SPEED_CADENCE_READING;
    this->bikeStateAttributes[static_cast<int>(BikeStateAttributeIndex::WHEEL_ROTATIONS_PER_MIN)].bikeStateAttributeType = BikeStateAttributeType::FLOAT_T;
    this->bikeStateAttributes[static_cast<int>(BikeStateAttributeIndex::CRANK_ROTATIONS)].bikeStateAttributeType = BikeStateAttributeType::SPEED_CADENCE_READING;
    this->bikeStateAttributes[static_cast<int>(BikeStateAttributeIndex::CRANK_ROTATIONS_PER_MIN)].bikeStateAttributeType = BikeStateAttributeType::FLOAT_T;
}

void BikeState::setAllMonitorAttributeType(MonitorAttributeType monitorAttributeType) {
    for (int i = 0 ; i < static_cast<int>(BikeStateAttributeIndex::BIKE_STATE_ATTRIBUTE_SIZE) ; i++ ) { 
        bikeStateAttributes[i].monitorAttributeType = monitorAttributeType;
    }
}

void BikeState::setAllLastFetchTimeTicks(uint32_t lastFetchTimeTicks) {
    for (int i = 0; i < static_cast<int>(BikeStateAttributeIndex::BIKE_STATE_ATTRIBUTE_SIZE); i++) {
        bikeStateAttributes[i].lastFetchTimeTicks = lastFetchTimeTicks;
    }
}

void BikeState::setAllAttributeValueOfType(BikeStateAttributeType bikeStateAttributeType, const BikeStateAttribute::BikeStateAttributeValue& bikeStateAttributeValue) {
    for (int i = 0; i < static_cast<int>(BikeStateAttributeIndex::BIKE_STATE_ATTRIBUTE_SIZE); i++) {
        if (bikeStateAttributes[i].bikeStateAttributeType == bikeStateAttributeType)
            bikeStateAttributes[i].bikeStateAttributeValue = bikeStateAttributeValue;
    }
}

bool BikeState::setStateAttribute(BikeStateAttributeIndex bikeStateAttributeIndex, BikeStateAttribute::BikeStateAttributeValue& bikeStateAttributeValue, uint32_t lastFetchTimeTicks) {
    this->bikeStateAttributes[static_cast<int>(bikeStateAttributeIndex)].bikeStateAttributeValue = bikeStateAttributeValue;    
    return this->setStateAttribute(bikeStateAttributeIndex, lastFetchTimeTicks);
}
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

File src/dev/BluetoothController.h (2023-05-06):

#ifndef _BLUETOOTH_CONTROLLER_H
#define _BLUETOOTH_CONTROLLER_H

#include <lvgl.h>
#include <ArduinoBLE.h>
#include <vector>
#include <algorithm>

#include "BluetoothBikeDefinitions.h"
#include "BluetoothBikeState.h"
#include "BluetoothBike.h"
#include "BluetoothScanner.h"
#include "BluetoothHeartRateMonitor.h"
#include "ConfigStore.h"

#define BATTERY_FIRMWARE_VERSION_MAJOR_NUMBER_BUFFER_INDEX 3
#define BATTERY_FIRMWARE_VERSION_MINOR_NUMBER_BUFFER_INDEX 2
#define BATTERY_FIRMWARE_VERSION_PATCH_NUMBER_BUFFER_INDEX 4

#define MOTOR_FIRMWARE_VERSION_MAJOR_NUMBER_BUFFER_INDEX 3
#define MOTOR_FIRMWARE_VERSION_MINOR_NUMBER_BUFFER_INDEX 2
#define MOTOR_FIRMWARE_VERSION_PATCH_NUMBER_BUFFER_INDEX 4

/**
 * @brief This represents the interface to the bike and is a wrapper for BLEDevice interface to the bikes.
 * 
 * The current implementation can only support a single instance of a connected Bike. Rather than allowing
 * multiple instances of BluetoothBikes to be discovered and connected to, but such functaionlity isn't needed here.
 * However, we've not put a restriction on the number of instances of BluetoothController instances 
 * (still only gonna be 1)!
 * 
 * The Controller has two basic modes, that of searching for BLEDevices that could be instances of BluetoothBikes, and 
 * that of attempting to connect to a BLEDevice as an instance of a BluetoothBike.
 * 
 */
class BluetoothController
{
private:
	/// <summary>
	/// This is helpful on processing handlers which will have to find the Controller the update is associated with
	/// </summary>
	static std::vector<BluetoothController*> bluetoothControllers;
public:
	/// <summary>
	/// This is the updateHandler static method called from BLEDevice for connection events
	/// </summary>
	static void connect_handler_cb(BLEDevice device);
	/// <summary>
	/// This is the updateHandler static method called from BLEDevice for disconnect events
	/// </summary>
	static void disconnect_handler_cb(BLEDevice device);

protected:
	/// <summary>
	/// This boolean identifies is scanning is required to be stopped before a connection is made
	/// </summary>
	bool connectionRequiresScanStop;	
	/// <summary>
	/// Bluetooth Device which is bike
	/// </summary>
	BluetoothBike* bluetoothBike;

	/// <summary>
	/// Bluetooth Device which is HRM
	/// </summary>
	BluetoothHeartRateMonitor* bluetoothHeartRateMonitor;

	/// <summary>
	/// Bluetooth Scanner
	/// </summary>
	BluetoothScanner* bluetoothScanner;

protected:
	/// <summary>
	/// This is the class callback for connection event
	/// </summary>	
	void updateConnectCB(BLEDevice device);
	/// <summary>
	/// This is the class callback for disconnect event
	/// </summary>	
	void updateDisconnectCB(BLEDevice device);

public:
	/// <summary>
	/// Constructor of the bluetooth controller object
	/// </summary>
	BluetoothController(BluetoothBike* bluetoothBike, BluetoothHeartRateMonitor* bluetoothHeartRateMonitor, BluetoothScanner* bluetoothScanner, bool connectionRequiresScanStop);

	/// <summary>
	/// Distructor of the bluetooth controller object
	/// </summary>
	~BluetoothController();

	BluetoothBike* getBluetoothBike() { return this->bluetoothBike; }

	BluetoothHeartRateMonitor* getBluetoothHeartRateMonitor() { return this->bluetoothHeartRateMonitor; }

	bool getConnectionRequiresScanStop() { return this->connectionRequiresScanStop; }

	bool getMultipleBtConnectionsAllowed() { return !this->connectionRequiresScanStop; }

	/// <summary>
	/// Check to see the state of the connections, Returns true if connecting to the bike
	/// </summary>
	/// <return>True if a BT device has been connected</return>
	bool checkForConnections(BTAddressesConfig* btAddressesConfig, bool connectBatteryOnly);

	void startConnections(lv_obj_t* listener_obj);

	void stopConnections();

	void stopScanning();
};

#endif

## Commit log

2022-10-09 At a mature enough state still issues with crashes
    [BluetoothBikeState.cpp]
2022-11-20 Documentation of Circuit and Enclosure
    Additional corrections on the Readme to point to correct versions of associated libraries
    [SpecializedDisplay.blend, SpecializedDisplayButtons.stl, SpecializedDisplayCase.stl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]
2022-12-01 Implemented assist level management
    As well as implementing assist level management clear up booting of the device.
2022-12-15 Finished work of Power Graph, rename the monitors
2022-12-18 Adding the small battery image and other fixes
    This represents a really stable version with 2 graphs and general motor condition displays
    [BluetoothBike.cpp]
2022-12-21 The addition of a few more medium monitors and fixing up some monitor issues
    [BTSpecializedDisplay.ino, BluetoothBike.cpp, LvglGui.cpp]
2023-01-23 Converting to use Arduino_LvGL_Glue
2023-03-21 Updates to T-DIsplay-S3 hence supporting different boards
2023-05-06 Improve organisation of managing and connecting to BT devices
2023-06-03 Update to get graph working correctly on TDISPLAY S3
    [lv_theme_TDISPLAY_S3.cpp]
2023-09-08 Update to the enclosure models
    [SpecializedDisplay_NanoRP2040Connect_SH107.blend, SpecializedDisplay_TDisplay.blend]
2023-09-10 Moved to right button being pressed as reset button
2023-09-10 Update to circuit documentation
2023-09-10 Fix for loss of connection not being detected
    [BTSpecializedDisplay.ino, BluetoothBike.cpp]
